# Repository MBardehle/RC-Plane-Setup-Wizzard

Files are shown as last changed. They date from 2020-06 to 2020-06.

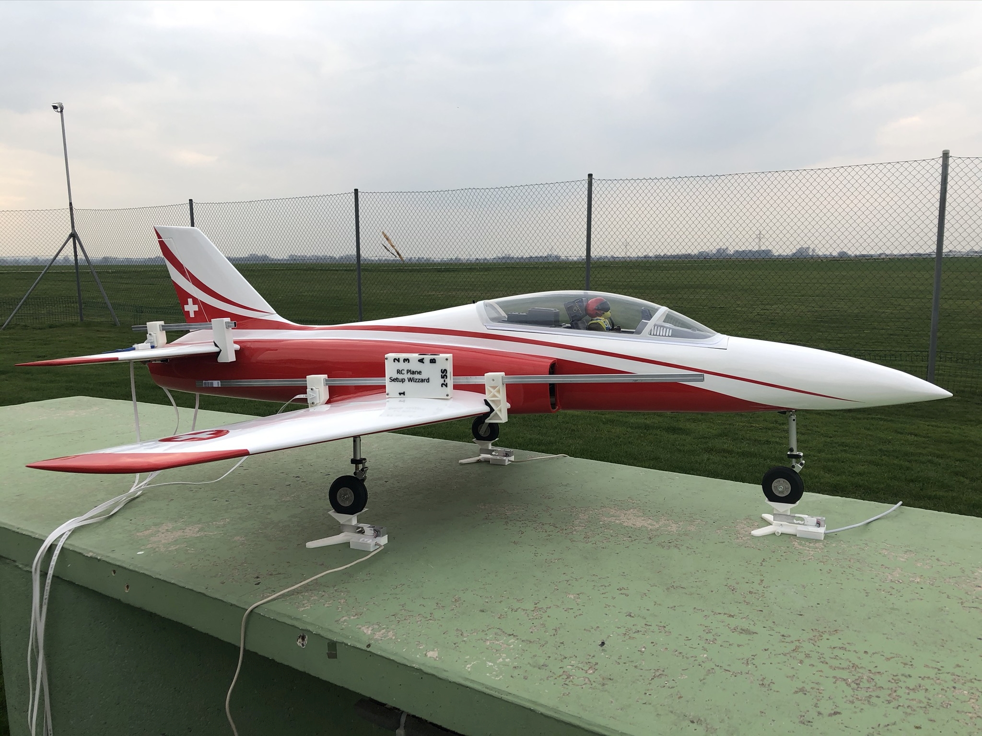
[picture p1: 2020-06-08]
Bilder/Titelbild.jpg

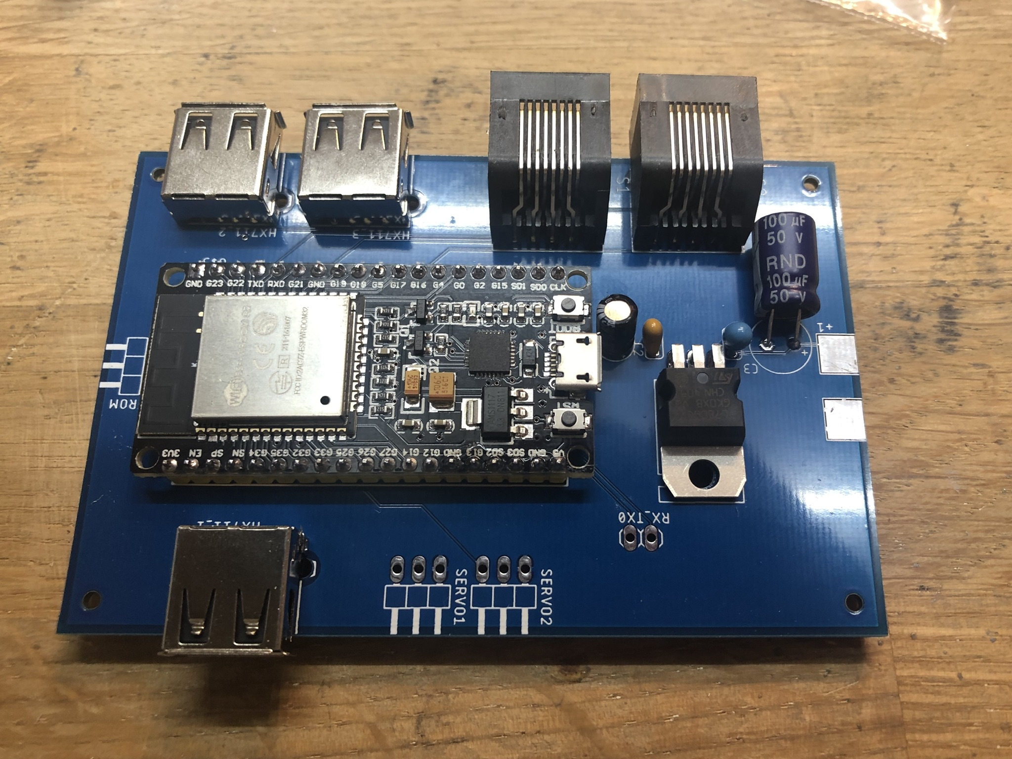
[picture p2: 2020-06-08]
Bilder/Platine.jpg

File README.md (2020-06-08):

# RC-Plane-Setup-Wizzard


Der RC Plane Setup Wizzard kann für die Einstellung der Einstellwinkeldifferenz (EWD), Ruderwinkel und Schwerpunktmessung bei Modellflugzeugen benutzt werden. 

Die benötigte Hardware besteht aus einem ESP32-Microcontroller , 3 Waagen und 2 Beschleunigungssensoren (MMA8451). Das Gehäuse ist für eine selbst erstellte Platine konstruiert worden. Diese kann gegen eine kleine Gebühr bei mir erworben werden. 

Die Sensordaten werden kabellos über eine Bluetooth-Verbindung an eine Android-App übermittelt und angezeigt.

Titelbild

Schwerpunktmessung
Schwerpunktmessung 3

Ruderwinkelmessung mit grafischer Anzeige auf Grenzwertverletzung
Rudermessung

Video_Start

EWD-Messung
EWD-Messung

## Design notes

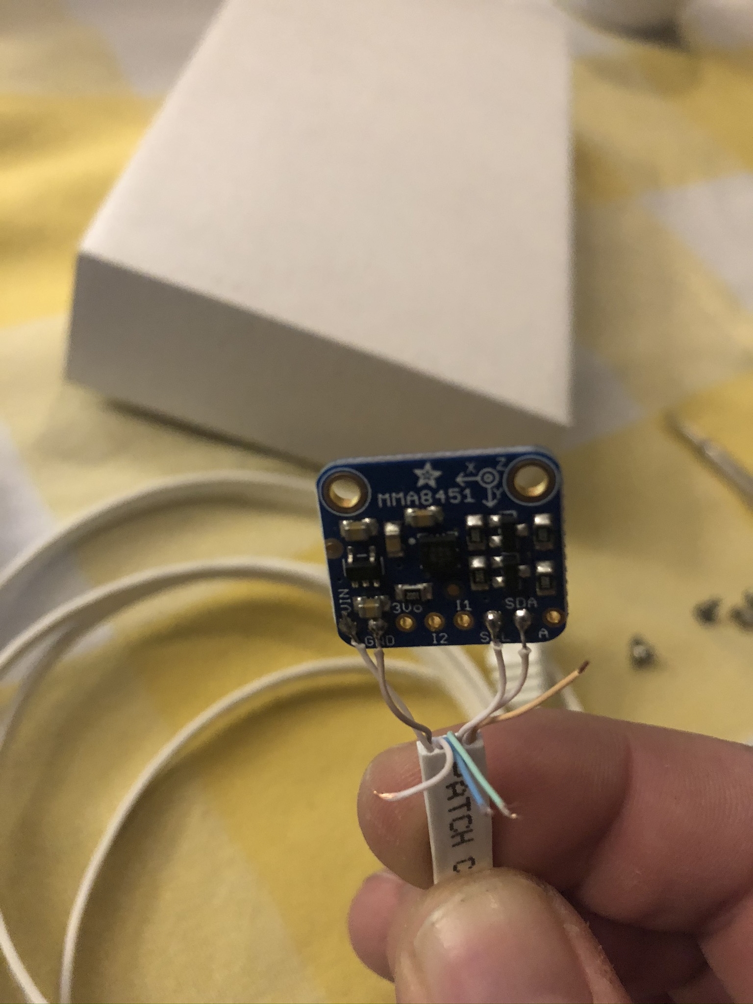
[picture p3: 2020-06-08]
Bilder/MMA8451_Verschaltung.jpg

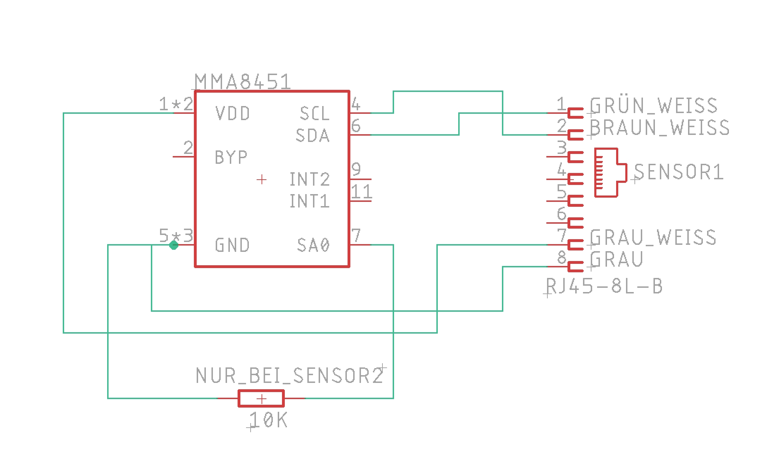
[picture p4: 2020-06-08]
Schaltpläne/Anschluss_MMA8451.jpg

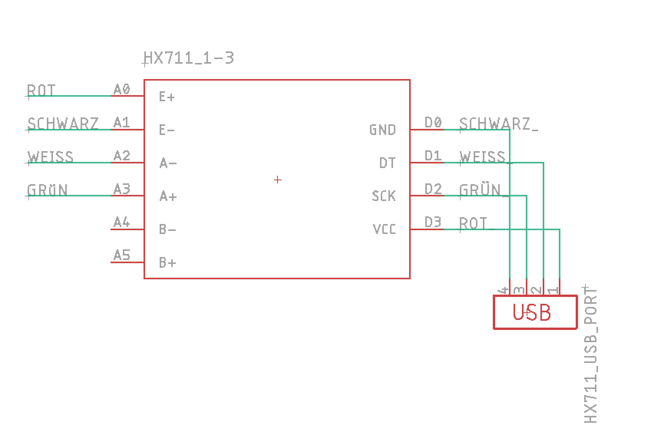
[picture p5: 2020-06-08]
Schaltpläne/Anschluss_HX711.jpg

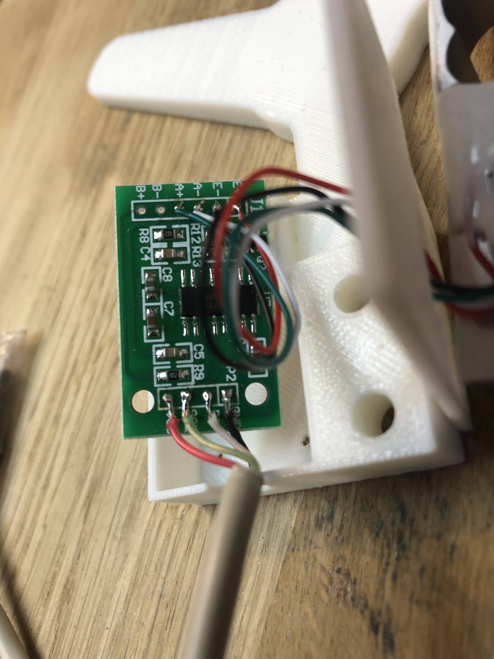
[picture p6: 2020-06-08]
Bilder/HX711_Verschaltung.jpg

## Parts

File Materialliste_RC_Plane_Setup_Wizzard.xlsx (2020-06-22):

Materialliste für RC Plane Setup Wizzard
Anzahl | Artikelbeschreibung | Einzelpreis | Gesamtpreis | Links
1 | 3m Cat.5e, Flach-Patchkabel, weiß | 1.95 € | 1.95 € | https://www.reichelt.de/3m-cat-5e-flach-patchkabel-weiss-goobay-93360-p171122.html?
1 | Widerstand 10k Ohm | 0.08 € | 0.08 € | https://www.reichelt.de/widerstand-kohleschicht-10-kohm-0207-250-mw-5-k-o-rd14jn103t52-p237396.html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
3 | USB 2.0 Kabel, High Speed A Stecker auf B Stecker, ca. 1,8 - 2,0 | 0.95 € | 2.85 € | https://www.reichelt.de/usb-2-0-kabel-high-speed-a-stecker-auf-b-stecker-ca-1-8-2-0-ak-672-2-2-0-p45866.html
2 | Entwicklerboards - Beschleunigungsmesser-Board, MMA8451Q | 9.50 € | 19.00 € | https://www.reichelt.de/entwicklerboards-beschleunigungsmesser-board-mma8451q-debo-sens-acc2-p235519.html
3 | USB-Einbaubuchse, Typ A, gewinkelt, Printmontage | 0.25 € | 0.75 € | https://www.reichelt.de/usb-einbaubuchse-typ-a-gewinkelt-printmontage-rnd-205-00856-p253047.html?
2 | RJ45 8P8C Ethernet Einbaubuchse | 0.42 € | 0.84 € | https://www.reichelt.de/rj45-8p8c-rnd-765-00013-p251918.html?
1 | ESP32 NodeMCU Module | 10.99 € | 10.99 € | https://www.az-delivery.de/products/esp32-developmentboard?_pos=12&_sid=d26cb81a0&_ss=r
1 | gutes ! Micro-USB-Kabel | 1.45 € | 1.45 € | https://www.reichelt.de/sync-ladekabel-usb-a-micro-usb-1-m-goobay-72227-p268018.html?trstct=pos_18&nbc=1
3 | Wiegezellen mit HX711 (Möglich sind 1Kg, 5Kg und 10 Kg) | 4.39 € | 13.17 € | https://www.banggood.com/5KG-Small-Scale-Load-Cell-Weighing-Pressure-Sensor-With-AD-HX711AD-Adapter-p-1129372.html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
1 | Platine für ESP32 (optional) | 15.00 € | 15.00 € | Mail an: marcel.bardehle@gmx.de
2 | Alu-Profil Vierkantprofil 12,5×7,5mm (Bauhaus oder Globus) | 2.05 € | 4.10 € | https://www.bauhaus.info/metallprofile-kunststoffprofile/kantoflex-rechteckrohr/p/10521929
1 | Laser Diode 3V 5mW 650nm rot (6mm dick) | 1.66 € | 1.66 € | https://www.ebay.de/itm/3V-Laser-Diode-5mW-650nm-NIR-nahes-Infrarot-ESP8266-Arduino-Raspberry-Pi/283491860699
1 | Schraubenset Linsenskopf M2.5 (M2.5 x 5 - M2.5x16) z.B. von Amazon | 11.90 € | 11.90 € | https://www.amazon.de/Haobase-Edelstahl-Hexagon-Schrauben-Schraube/dp/B07RBTGT7B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
1 | Schrauben Sonstige (M2.5x6 Senkkopf, M5x20 Senkkopf, M4x16 Zylinderkopf) | 3.00 € | 3.00 €
1 | Set Messing Einpressmuttern M2.5 x 4 x 3.5 (100 Stück) | 7.49 € | 7.49 € | https://www.amazon.de/gp/product/B07SYP6PRJ/ref=ppx_yo_dt_b_asin_title_o09_s00?ie=UTF8&psc=1
1 | Magnet 10 x 2 mm Rund oder Eckig | 1.00 € | 1.00 € | Ebay/Amazon/Hobbyking
 | Kosten für 3D Druck Filament (ca. 500Gramm) |  | 10.00 €
 | Gesamtkosten für das Projekt |  | 105.23 €
Schrauben
Neigungssensoren
Anzahl | Größe
8 | M2.5 x4 Zylinderkopfschraube Neigungssensoren Deckel und Platine
4 | M2.5 x 6 Senkkopfschraube Neigungssensor Boden
4 | M2.5 x 16 Zylinderkopfschraube Verschraubung Neigungssensor mit EWD-Halter
4 | Messing Einpressmuttern M2.5 x 5
Waagen
6 | M5x20 Senkkopfschrauben
6 | M4x16 Zylinderkopfschraube
Gehäuse
4 | M2.5x12 Zylinderkopfschraube
4 | M2.5x5 Zylinderkopfschraube für Platine

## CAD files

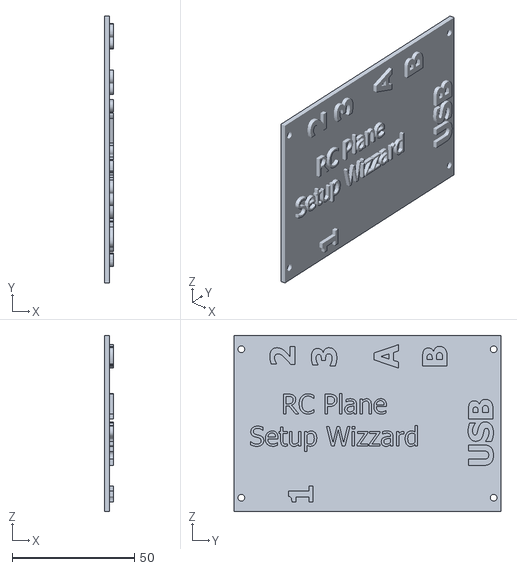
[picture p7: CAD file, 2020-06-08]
3D Files/Gehäuse/Deckel_V11_USB.stl
3.50 x 109.0 x 72.0

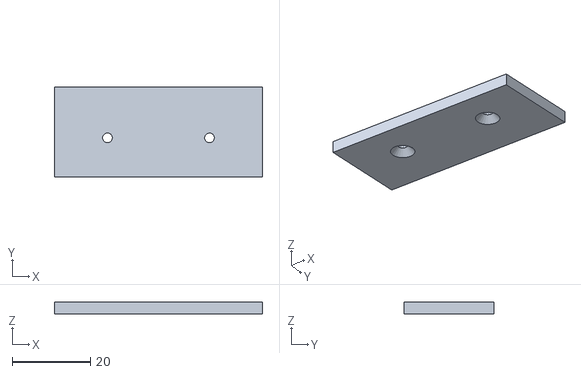
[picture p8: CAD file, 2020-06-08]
3D Files/Neigungssensor/2x Adapter Rudermessung.stl
53.0 x 23.0 x 3.00

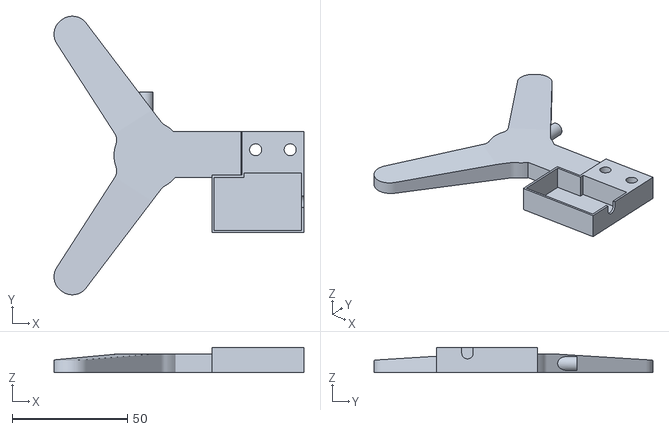
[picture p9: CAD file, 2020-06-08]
3D Files/Waagen/Gehäuse Waage 3 Ziel.stl
108.6 x 121.0 x 11.0

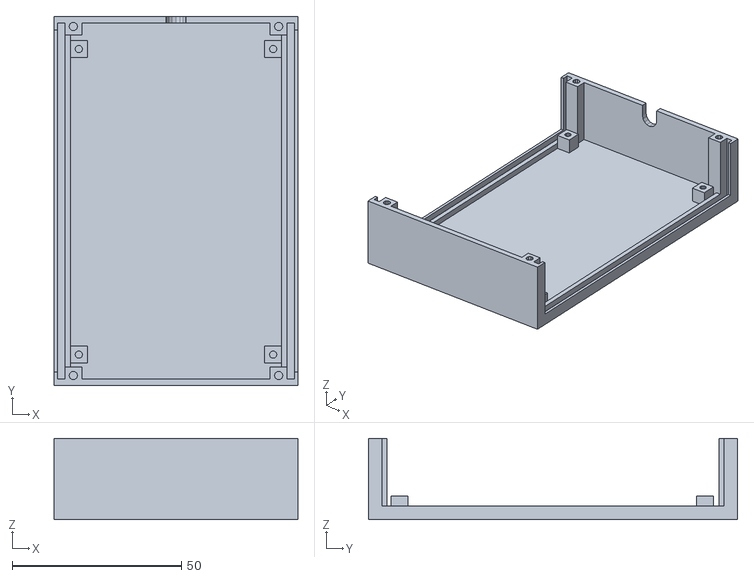
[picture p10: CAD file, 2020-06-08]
3D Files/Gehäuse/Box_USB.stl
72.0 x 109.0 x 24.0

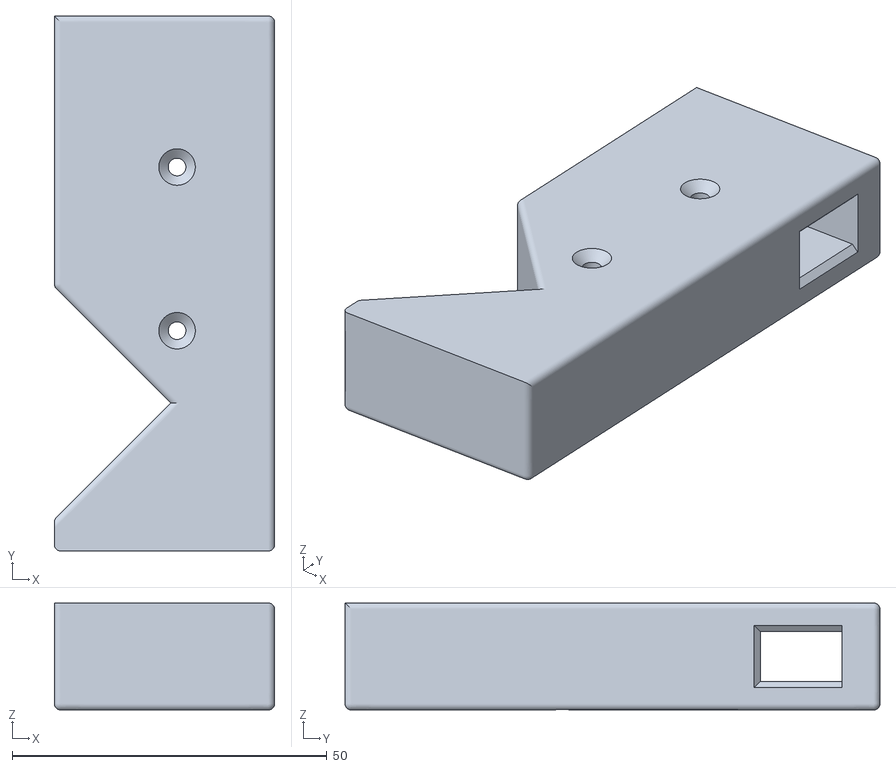
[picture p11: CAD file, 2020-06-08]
3D Files/Neigungssensor/2x EWD_SensorArm_hinten.stl
35.0 x 85.0 x 17.0

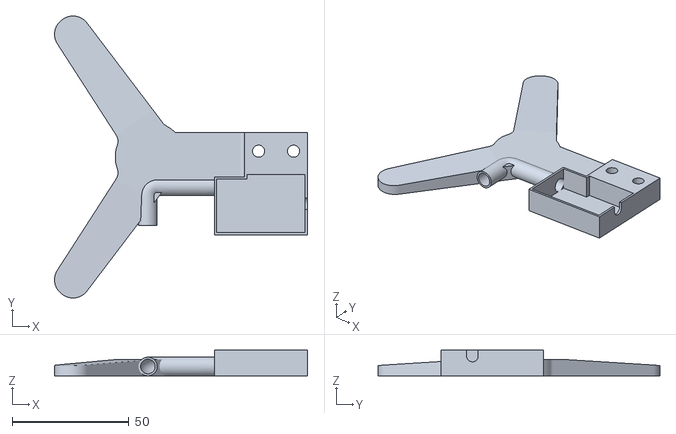
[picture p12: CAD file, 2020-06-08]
3D Files/Waagen/Gehäuse Waage 2 Laser.stl
108.6 x 121.0 x 11.0

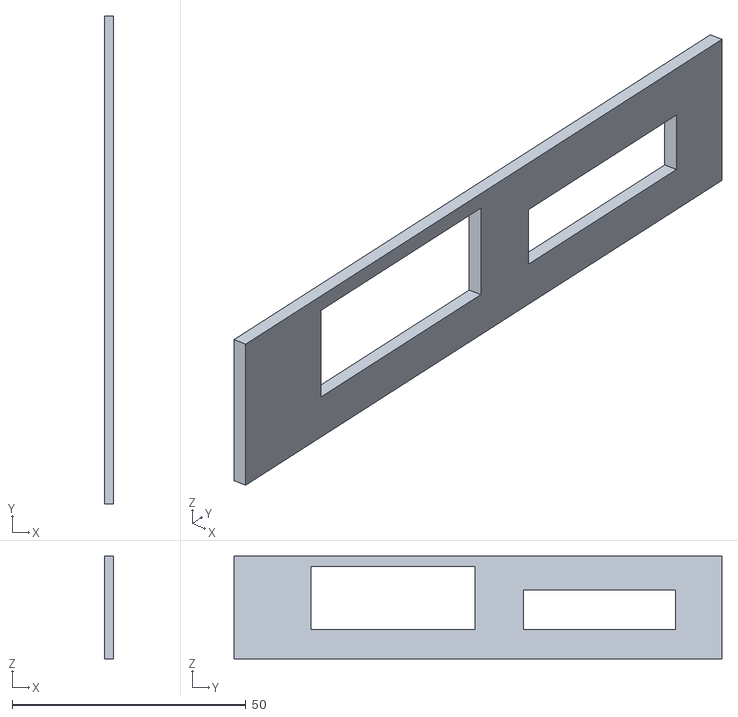
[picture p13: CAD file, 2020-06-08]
3D Files/Gehäuse/Seitenteil_Rechts.stl
2.00 x 104.5 x 22.0

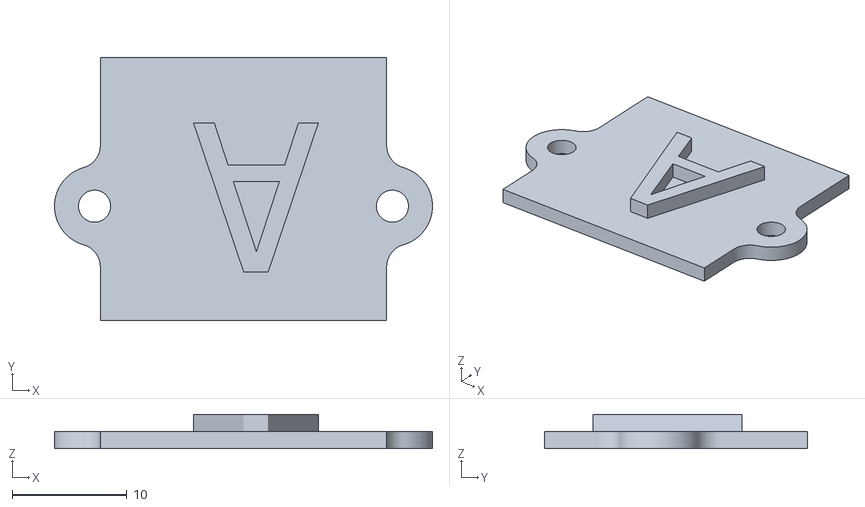
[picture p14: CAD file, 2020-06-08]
3D Files/Neigungssensor/EWD_Deckel_A.stl
33.0 x 23.0 x 3.00

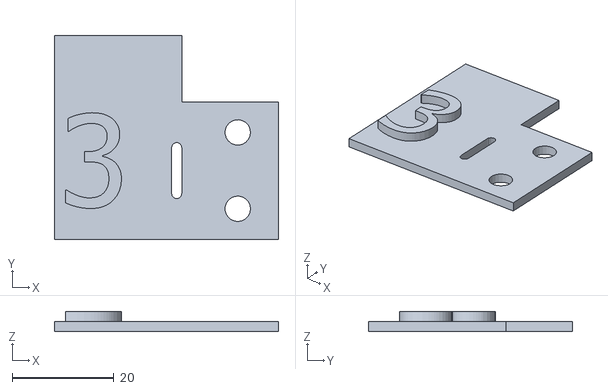
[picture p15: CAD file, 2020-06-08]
3D Files/Waagen/Deckel_3.stl
44.0 x 40.0 x 4.00

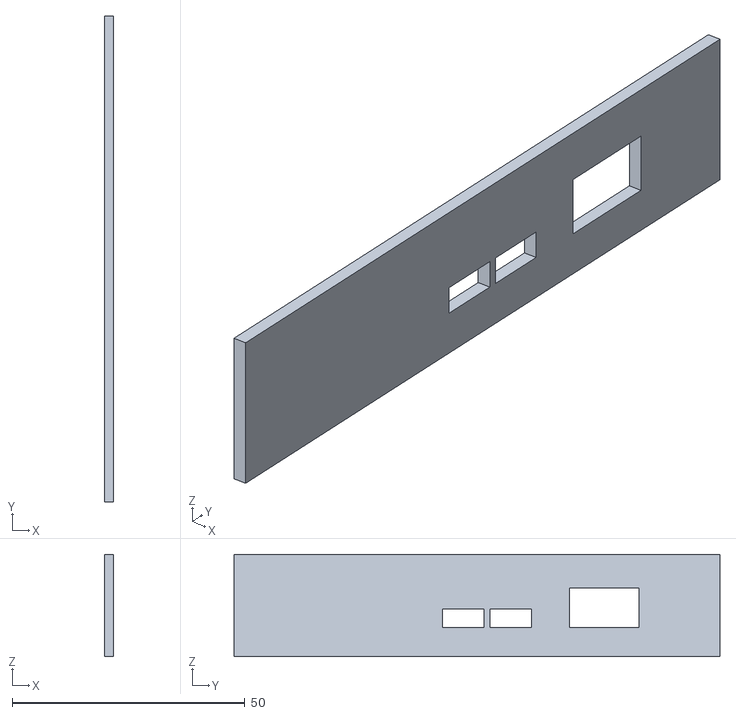
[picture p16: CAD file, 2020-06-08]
3D Files/Gehäuse/Seitenteil_Links.stl
2.00 x 104.5 x 22.0

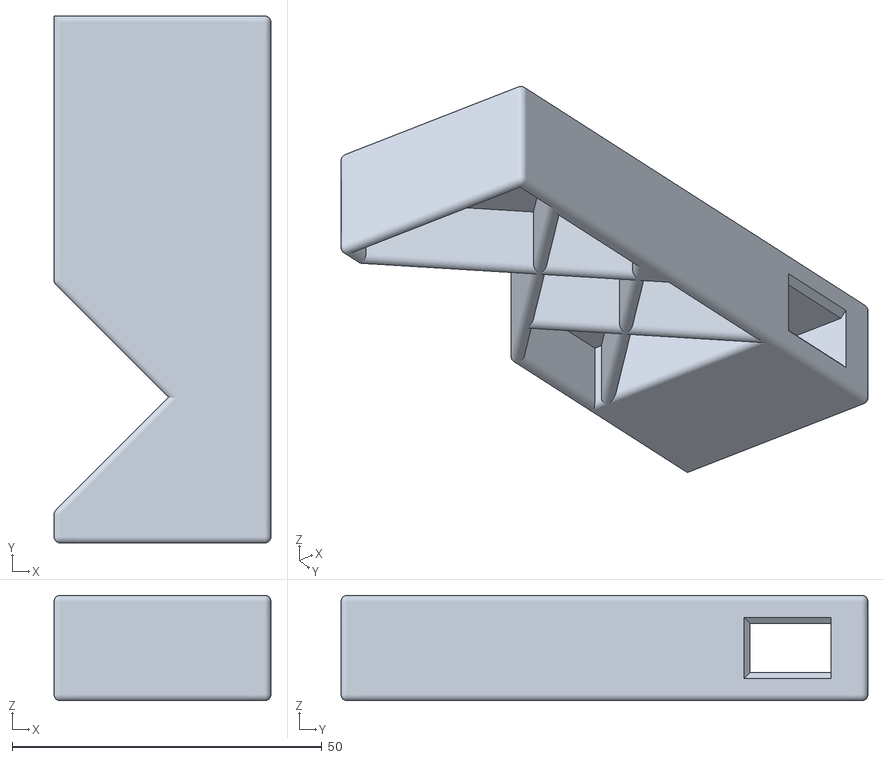
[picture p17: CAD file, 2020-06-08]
3D Files/Neigungssensor/2x EWD_Arm_Vorne.stl
35.0 x 85.0 x 17.0

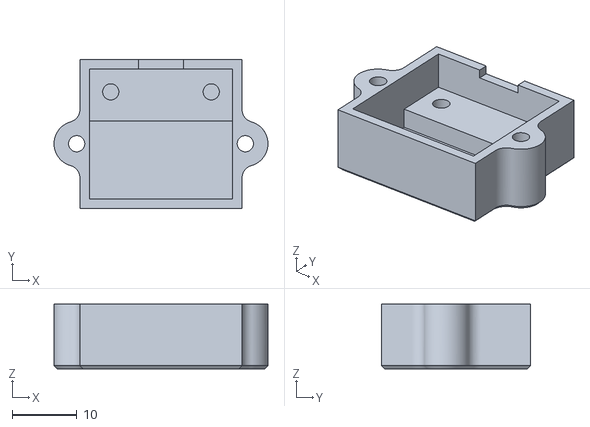
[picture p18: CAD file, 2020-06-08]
3D Files/Neigungssensor/2x EWD_Gehäuse_Sensor.stl
33.0 x 23.0 x 10.0

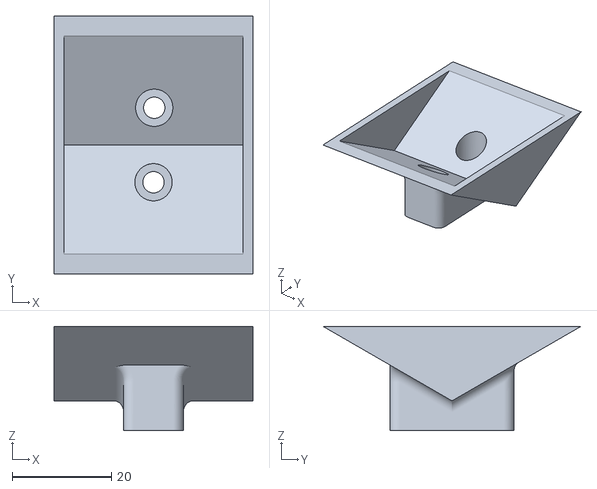
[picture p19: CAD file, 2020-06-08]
3D Files/Waagen/3x Wanne_Eckig.stl
40.0 x 52.0 x 21.0

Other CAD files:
3D Files/Neigungssensor/EWD_Deckel_B.stl
3D Files/Waagen/Deckel_2.stl
3D Files/Waagen/Gehäuse Waage 1 ohne Laser.stl
3D Files/Waagen/Deckel_1.stl

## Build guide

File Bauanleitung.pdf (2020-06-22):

RC Plane Setup Wizzard | Bauanleitung

1

# Bauanleitung RC Plane Setup Wizzard

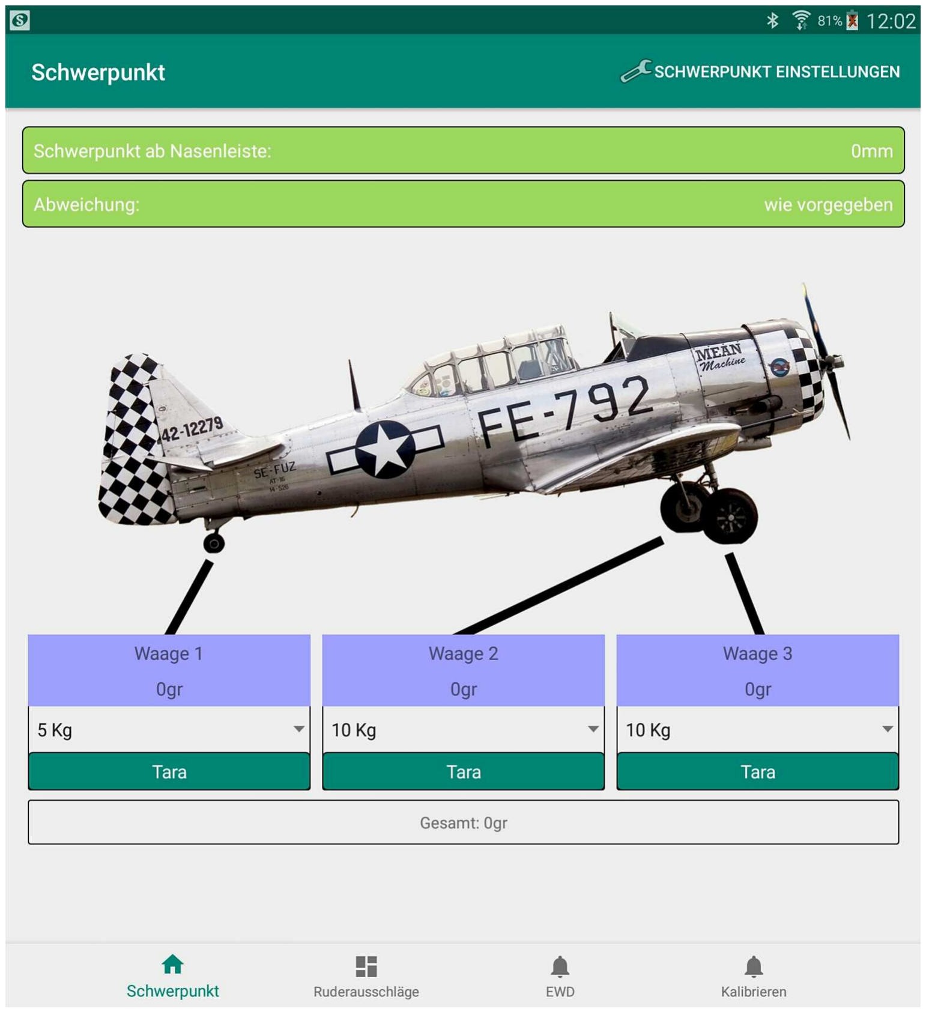
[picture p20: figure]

2

Inhaltsverzeichnis

3

### Vorwort

Das vorliegende Benutzerhandbuch soll Ihnen helfen, die Funktionen des „RC Plane Setup Wizzard“ zu verstehen und das System bedienen zu können. Das Mess-System ist aus der Projektarbeit „PAMF“ (Pilotierung eines appbasierten Messsystems für Fluggeräte) mit den weiteren Personen Gernot Goetz und Thomas Aulich entstanden und wurde nach Fertigstellung der Entwicklung mit dem Produktnamen „RC Plane Setup Wizzard“ betitelt.

Der RC Plane Setup Wizzard ist ein Hilfsmittel, Modellflugzeuge mit Tragflächen vor dem Flug am Boden auszumessen und einstellen zu können. Ein gut eingestelltes Flugmodel nutzt die konstruktionsbedingten Eigenschaften bestmöglich aus. Ein schlecht eingestelltes Flugmodel führt zu schlechten Flugeigenschaften und ggf. zum Absturz. Durch einen Absturz hervorgerufene Schäden können abhängig vom Fluggerät sehr kostspielig sein. Im schlimmsten Fall droht der Totalverlust.

Die folgenden Parameter können mit dem RC Plane Setup Wizzard eingestellt werden:

### 1. Einstellwinkeldifferenz (EWD) zwischen Tragflächen und Höhenruder

### 2. Einstellung des Schwerpunkts auf die errechnete Position

### 3. Einstellung der maximalen Ruderausschläge für die Höhen- und Querruder

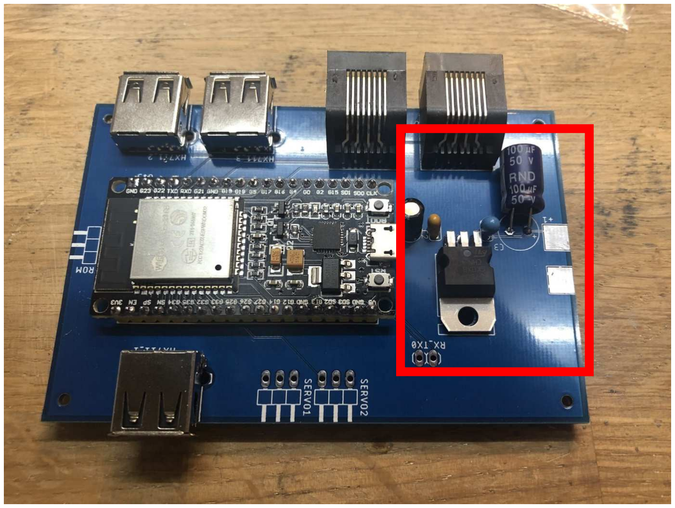
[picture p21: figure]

4

### Aufbau der Platine

Die fertige Platine wird mit folgenden Komponenten bestückt:
- ESP32
- 3x USB Buchse
- 2x RJ-45 Buchse

Es muss genau auf die Ausrichtung des ESP32 geachtet werden.
Die weiteren Bauteile in dem rot markierten Feld werden nicht benötigt.

Die Spannungsversorung des Systems erfolgt direkt über das USB-Kabel, welches am ESP32 angeschlossen wird.

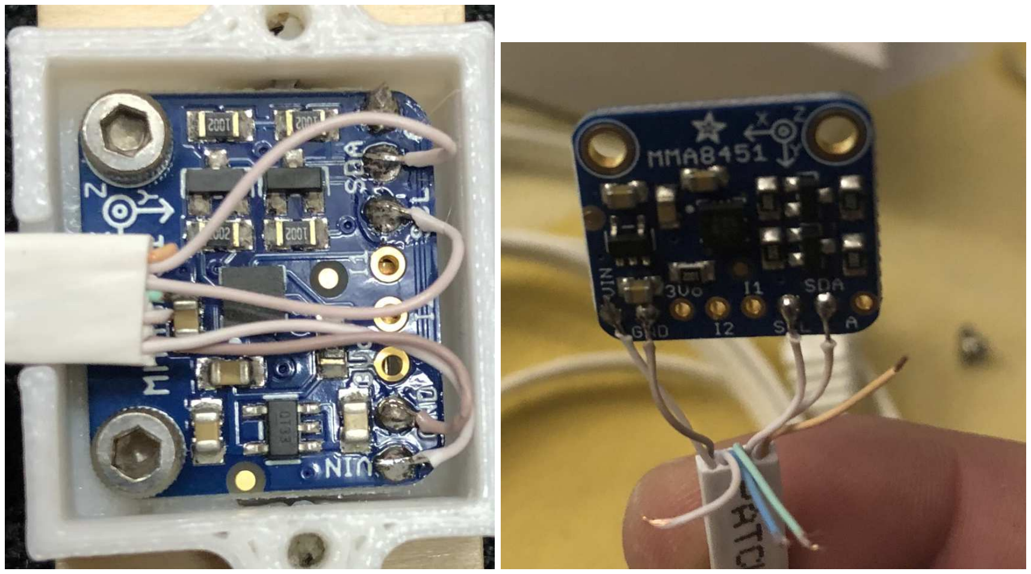
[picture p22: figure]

5

### Aufbau der Neigungssensoren MMA 8451

### 1. Von der Unterseite werden die M2.5 Messing-Einpressmuttern mit einem

Lötkolben bündig mit der Unterseite eingeschmolzen.

### 2. Die Neigungssensoren MMA8451 werden mit M2.5x4 Schrauben im Gehäuse

befestigt.

### 3. Das Ethernet-Kabel mittig durchschneiden. Die Kabellänge von 1,5m je

Sensor darf dabei nicht überschritten werden.
4. Ethernet-Kabel wie auf dem Foto zu sehen anlöten.
5. Für Sensor B einen 10kOhm Widerstand zwischen A und GND anlöten.
6. Verdrahtung gemäß der Tabelle mit Multimeter auf Durchgang prüfen.

Die Adern des Ethernet-Kabels treten immer als Paar auf. Zu jeder Farbe befindet sich auch ein weißer Draht. Mit der Bezeichnung grün/weiß ist der weiße Draht gemeint der zusammen mit dem grünen Draht ein Pärchen ergeben. Die Paare sind nach abisolieren des Kabels zu erkennen.

Pin Sensor | Kabelfarbe | Pin am ESP32
VIN | Grau/Weiss | 3V3
GND | Grau | GND
SDA | Grün/Weiss | 21
SCL | Gelb/Weiss | 22

Auf die RJ45-Buchsen sind zusätzlich die Pins 16/17 verschaltet. Hier ist der 2. I2C-Bus des ESP32 angeschlossen. Diese Pins können für optionale Erweiterungen genutzt werden.

Das flache Ethernet-Kabel kann nach dem Verlöten mit einem Tropfen Sekundenkleber am Gehäuse fixiert werden.

### Aufbau der Wiegeelemente

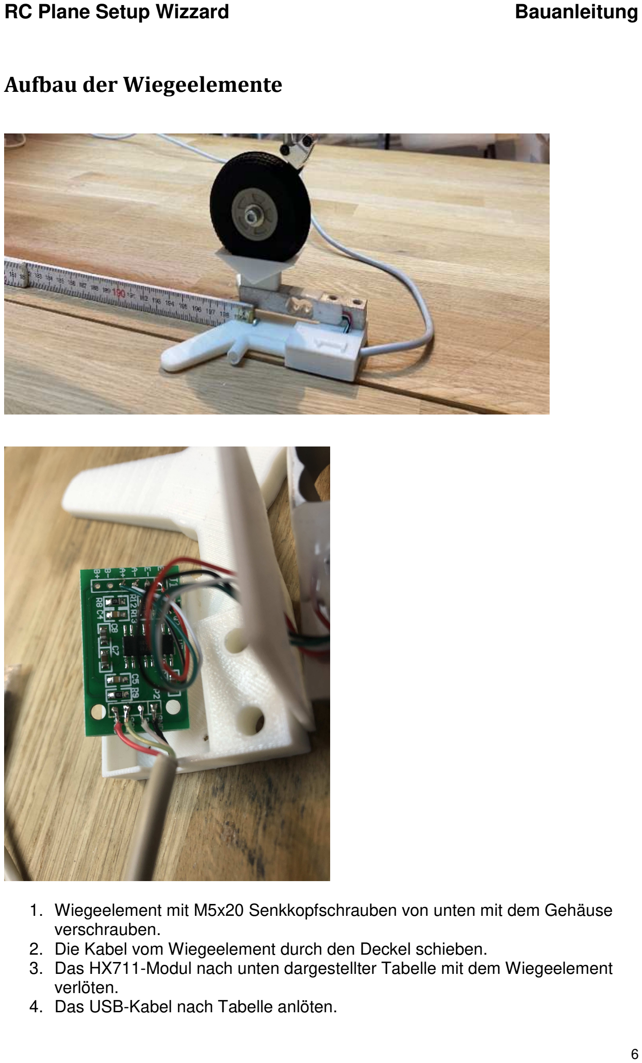
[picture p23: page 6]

6

### 1. Wiegeelement mit M5x20 Senkkopfschrauben von unten mit dem Gehäuse

verschrauben.
2. Die Kabel vom Wiegeelement durch den Deckel schieben.

### 3. Das HX711-Modul nach unten dargestellter Tabelle mit dem Wiegeelement

verlöten.
4. Das USB-Kabel nach Tabelle anlöten.

7

Beim Wiegeelement mit Laser müssen folgende Arbeiten zusätzlich durchgeführt werden
a. Am Laser überstehende Reste vom werksseitigen Löten abschleifen, sodass dieser komplett rund ist.
b. Kabel und Laser in Gehäuse bauen. Laser halb in Gehäuse einschieben, damit später der Fokus noch eingestellt werden kann.
c. Rotes Kabel an VCC / Blaues Kabel an GND anlöten
d. Ausrichtung und Fokus testen
e. Der Fokus kann über die Linse vorne am Laser eingestellt werden. Es sollte ein kleiner starker Punkt ca. 25cm vom Laser entfernt, eingestellt werden. In den meisten Fällen sind die Laser bereits passend voreingestellt.
5. Das Modul mit doppelseitigem Klebeband im Gehäuse fixieren.

### 6. Wiegeelement mit M5x20 Senkkopfschrauben von unten mit dem Gehäuse

verschrauben.

### 7. Reifenwanne vorne mit Waage verschrauben

a. Bei Waage 1 einen Magnet mit den Maßen 10x2mm in den Anschlag für den Zollstock kleben.
Kabelfarbe Waage | Pin am HX711
Rot | E+
Schwarz | E-
Weiß | A-
Grün | A+
Pin HX711 | Kabelfarbe USB | Pin am ESP32
VCC | Rot | 3V3
SCK | Grün | Waage 1: 26
| | Waage 2: 18
| | Waage 3: 32
DT | Weiss | Waage 1: 27
| | Waage 2: 19
| | Waage 3: 33
GND | Schwarz | GND

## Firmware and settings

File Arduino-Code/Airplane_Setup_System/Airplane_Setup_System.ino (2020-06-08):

#include "BluetoothSerial.h"
#include "EWD.h"
#include "CG.h"
#include "Arduino.h"
#include <inttypes.h>


EWD ewd;          //Sensor EWD einfügen
CG cg;            //Schwerpunktwaage einfügen
String btMessage;
String SerialMessage;
bool CG_initOK=false;
bool EWD_initOK=false;
bool RUD_initOK=false;
String function;
String sensor;
String instruction1;
String instruction2;
long timerSend=0.0;
int delaySend=200;

#if !defined(CONFIG_BT_ENABLED) || !defined(CONFIG_BLUEDROID_ENABLED)
#error Bluetooth is not enabled! Please run `make menuconfig` to and enable it
#endif

BluetoothSerial SerialBT;

void setup() {
  Serial.begin(115200);
  SerialBT.begin("Air"); //Bluetooth device name
  Serial.println("The device started, now you can pair it with bluetooth!");
  
  ewd.init();
  cg.init();
}

void loop() {

//Serial.println(btMessage);
char outputText[100];
int i;
int startChar;
int endChar[3];
int endCharCounter=0;
int messageEnd;
long Startmillis;
 if (SerialBT.available()){      // Daten liegen an
   Startmillis=millis();
   
    btMessage = SerialBT.readString(); // Nachricht lesen
    Serial.println(btMessage);
    btMessage.toCharArray(outputText,btMessage.length()+1);     //Zum kopieren muss die Länge +1 genutzt werden, da ansonsten das letzte Zeichen abgeschnitten wird.
    endCharCounter=0;
    messageEnd=0;
    Serial.println(millis()-Startmillis);
    
    for(i=0;i<=btMessage.length();i++)                           //Nach Trennzeichen suchen und Position in endChar-Array speichern
    {
      if(outputText[i]=='#')
      {
        endChar[endCharCounter]=i;
        endCharCounter++;
      }
      if(outputText[i]==';')
      {
        messageEnd=i;
        i=btMessage.length();
      }
    }
    
//  Serial.print("EndChar: ");Serial.println(endCharCounter);  
  function = btMessage.substring(0, endChar[0]);              //Von 0 bis 1. Trennzeichen ist die Funktion
  sensor = btMessage.substring(endChar[0]+1, endChar[1]);     //Von 1.Trennzeichen +1 bis 2. Trennzeichen ist Sensor
  if(endCharCounter>2)                                        //Prüfen ob mehr als 2 Trennzeichen
  {
  instruction1 = btMessage.substring(endChar[1]+1, endChar[2]);         //3 Trennzeichen für Instruction 1 + 2
  instruction2 = btMessage.substring(endChar[2]+1, messageEnd);    
  }
  else{
  instruction1 = btMessage.substring(endChar[1]+1, messageEnd);  //Nur 2 Trennzeichen
  instruction2 = "";
  }
 Serial.print("Function: ");Serial.println(function); 
Serial.print("Sensor: ");Serial.println(sensor);
Serial.print("Instruction 1: ");Serial.println(instruction1);
Serial.print("Instruction 2: ");Serial.println(instruction2);
 endChar[0]=0;
 endChar[1]=0;
 endChar[2]=0;
 messageEnd=0;
 }

if (Serial.available()){      // Daten liegen an
    SerialMessage = Serial.readString(); // Nachricht lesen
    if(SerialMessage == "CG Set Default\n"){
      cg.set_Defaults();
      SerialMessage="";
      cg.init();
    }
    if(SerialMessage == "EWD Set Default\n"){
      ewd.set_Defaults();
      SerialMessage="";
      ewd.init();
    }
}


/***********STring splitten*****/
//  function = btMessage.substring(0, 2);
//  sensor = btMessage.substring(4, 5); 

  if(function=="CG"){
    //Serial.println("if CG Funktion");
    CG_Comm();
  }

  if(function=="EWD"){
    //Serial.println("if CG Funktion");
    EWD_Comm();
  }

  if(function=="RUD"){
    //Serial.println("if CG Funktion");
    RUD_Comm();
  }

}

void CG_Comm(){
  
  int i;
  char outputText[100];
  float calFactor;

  EWD_initOK=false;   //Init der anderen Funktionen zurücksetzen
  RUD_initOK=false;

/* Start Werte automatisch senden */
  if(sensor=="0"&& instruction1=="START"){
    if(CG_initOK==false){
    cg.init(); 
    CG_initOK=true;
    SerialBT.println("CG#0#Start#OK;");
    Serial.println("CG#0#Start#OK;");
    for(i=1;i<=3;i++){
      sprintf(outputText,"CG#%i#%i;", i,cg.get_ldcell_Maxweight(i));
      SerialBT.println(outputText);  
      }
    }
  cg.readSensor();
  sprintf(outputText,"CG#1#%.1f#2#%.1f#3#%.1f;", cg.get_weight(1),cg.get_weight(2),cg.get_weight(3));
  SerialBT.println(outputText);
  Serial.println(outputText);
  
  }

/**** Waage Max-Gewicht setzen ****/  
  if(instruction1=="SET"){          //CG#1#SET#1
    //Serial.print("Sensor: ");Serial.println(sensor.toInt());
    //Serial.print("Inst2: ");Serial.println(instruction2.toInt());
    cg.set_ldcell_Maxweight(sensor.toInt(),instruction2.toInt());
     cg.init(); 
    sprintf(outputText,"CG#%i#SET#%i#OK;", sensor.toInt(), instruction2.toInt());
      SerialBT.println(outputText);  
      Serial.println(outputText);
  function="";
  instruction1="";
  instruction2="";
  }

/*** Waagen nullen ***/
  if(instruction1=="ZERO"){          //CG#0#ZERO
 Serial.println(instruction1);
 
    if(sensor.toInt()==0){
    bool zero1=cg.setZero(1);
    bool zero2=cg.setZero(2);
    bool zero3=cg.setZero(3);
    Serial.print(zero1);Serial.print(zero2);Serial.println(zero3);
      if (zero1==true&&zero2==true&&zero3==true){
        sprintf(outputText,"CG#%i#ZERO#OK;", sensor.toInt());
        SerialBT.println(outputText);  
        Serial.println(outputText);
        }
        else{
        sprintf(outputText,"CG#%i#ZERO#ERROR;", sensor.toInt());
        SerialBT.println(outputText);  
        Serial.println(outputText);    
        }
    }
    else{
      bool zero=cg.setZero(sensor.toInt());
      if (zero==true){
        sprintf(outputText,"CG#%i#ZERO#OK;", sensor.toInt());
//        SerialBT.println(outputText);  
        Serial.println(outputText);
      }
      else{
        sprintf(outputText,"CG#%i#ZERO#ERROR;", sensor.toInt());
//        SerialBT.println(outputText);  
        Serial.println(outputText);    
        }
      
    }
    
  function="CG";
  sensor="0";
  instruction1="START";
  instruction2="";
  }

/*****Status Waage abfragen*/
if(instruction1=="STATUS"){          //CG#1#STATUS--> CG#1#Gewicht#Max-Gewicht#Kalibrierfaktor
  int maxWeight=cg.get_ldcell_Maxweight(sensor.toInt());
  calFactor=cg.getCalFactor(sensor.toInt(),maxWeight);    
  cg.readSensor();    
//  cg.get_weight(1)(sensor.toInt());
    sprintf(outputText,"CG#%i#%.1f#%i#%.2f;", sensor.toInt(),cg.get_weight(sensor.toInt()),maxWeight,calFactor);
      SerialBT.println(outputText);  
      Serial.println(outputText);
  function="";
  instruction1="";
  instruction2="";
  }

/****Kalibrierfaktor auslesen*/
if(instruction1=="GETFAKTOR"){          //CG#1#GETFAKTOR#1
    //Serial.print("Sensor: ");Serial.println(sensor.toInt());
    //Serial.print("Inst2: ");Serial.println(instruction2.toInt());
    calFactor=cg.getCalFactor(sensor.toInt(),instruction2.toInt()); 
    sprintf(outputText,"CG#%i#%i#%.2f;", sensor.toInt(),instruction2.toInt(),calFactor);
      SerialBT.println(outputText);  
      Serial.println(outputText);
  function="";
  instruction1="";
  instruction2="";
  }

/****Kalibrierung Waage frei setzen*/
if(instruction1=="READY"){          //CG#1#READY
cg.startCalibration(sensor.toInt());  
    sprintf(outputText,"CG#%i#READY#OK;", sensor.toInt());
      SerialBT.println(outputText);  
      Serial.println(outputText);
  function="";
  instruction1="";
  instruction2="";
  }


/****Kalibrierung mit Kalibriergewicht*/
if(instruction1=="CAL"){          //CG#1#CAL#Kalibriergewicht in Gramm
cg.calibrateWithKnownWheigt(sensor.toInt(),instruction2.toInt());  
    sprintf(outputText,"CG#%i#CAL#OK;", sensor.toInt());
      SerialBT.println(outputText);  
      Serial.println(outputText);
  function="";
  instruction1="";
  instruction2="";
  }

/****Kalibrierfaktor manuell Anpassen */  
if(instruction1=="ADDFAKTOR"){          //CG#1#ADDFAKTOR#Wert
cg.fineTuneCal(sensor.toInt(),instruction2.toInt());  
    sprintf(outputText,"CG#%i#ADDFAKTOR#OK;", sensor.toInt());
      SerialBT.println(outputText);  
      Serial.println(outputText);
  function="";
  instruction1="";
  instruction2="";
  }  
}


void EWD_Comm(){
  int i;
  char outputText[50];
  bool calOK=false;
  RUD_initOK=false;         //Init der anderen Funktionen zurücksetzen
  
  
/* Start Werte automatisch senden */
  if(sensor=="0"&& instruction1=="START"){
    if(EWD_initOK==false){
    EWD_initOK=ewd.init(); 
      if(EWD_initOK==true){
        SerialBT.println("EWD#0#START#OK;");
        Serial.println("EWD#0#START#OK;");    
        }
        else{
        SerialBT.println("EWD#0#START#ERROR;");
        Serial.println("EWD#0#START#ERROR;");
          function="";
          instruction1="";
          instruction2="";        
        }
    }
  if(EWD_initOK==true){
  ewd.readSensor();
  sprintf(outputText,"EWD#A#%.1f#B#%.1f#AB#%.1f;", ewd.get_SensorA(),ewd.get_SensorB(),ewd.get_SensorDiff());
  SerialBT.println(outputText);
  Serial.println(outputText);
    }
  }

/*** Neigunssensoren nullen ***/
  if(instruction1=="ZERO"){          //EWD#0#ZERO
    if(sensor=="0"){
    ewd.zeroingFunction('A');
    ewd.zeroingFunction('B');
    sprintf(outputText,"EWD#0#ZERO#OK;");
        SerialBT.println(outputText);  
        Serial.println(outputText);
    }   

    if(sensor=="A"){
    ewd.zeroingFunction('A');
    sprintf(outputText,"EWD#A#ZERO#OK;");
        SerialBT.println(outputText);  
        Serial.println(outputText);
    }
    
    if(sensor=="B"){
    ewd.zeroingFunction('B');
    sprintf(outputText,"EWD#B#ZERO#OK;");
        SerialBT.println(outputText);  
        Serial.println(outputText);
    }
  

  function="";
  sensor="";
  instruction1="";
  instruction2="";
  
  /*
  function="EWD";
  sensor="0";
  instruction1="START";
  instruction2="";
  */
 // EWD_initOK=false;
  }
  
/******Sensor A kalibrieren ***/
  if(sensor=="A"&&instruction1=="CAL"){
    calOK= ewd.calibrateSensor(1,SerialBT);
      if(calOK==true){
      SerialBT.println("EWD#A#CAL#OK;");
      Serial.println("EWD#A#CAL#OK;");
      }
      else{
      SerialBT.println("EWD#A#CAL#ERROR;");
      Serial.println("EWD#A#CAL#ERROR;");
      }
    function="";
    instruction1="";
    instruction2="";
  }

/******Sensor B kalibrieren ***/ 
  if(sensor=="B"&&instruction1=="CAL"){
    calOK= ewd.calibrateSensor(2,SerialBT);
      if(calOK==true){
      SerialBT.println("EWD#B#CAL#OK;");
      Serial.println("EWD#B#CAL#OK;");
      }
      else{
      SerialBT.println("EWD#B#CAL#ERROR;");
      Serial.println("EWD#B#CAL#ERROR;");
      }
    function="";
    instruction1="";
    instruction2="";
    }    
} /**Ende EWD-Comm



/***Ruder-Messung */
/* Die Ruder-Messung ist in die Klasse EWD eingebunden, da auf die gleichen Sensoren zugegriffen wird.
 *  Die Funktionen für die Rudermessung fangen mit dem Kürzel "RUD_" an.
 *  Die Initilisierung ist die gleiche wie bei der EWD-Messung
 */
void RUD_Comm(){
  int i;
  char outputText[50];

  EWD_initOK=false;         //Init der EWD-Funktion zurücksetzen
  
/* Start Werte automatisch senden */
  if(sensor=="0"&& instruction1=="START"){
    if(RUD_initOK==false){
    RUD_initOK=ewd.init(); 
    if(RUD_initOK==true){
      ewd.RUD_readSensor();
      //ewd.RUD_zeroingFunction('A');
      //ewd.RUD_zeroingFunction('B');
      SerialBT.println("RUD#0#START#OK;");
      Serial.println("RUD#0#START#OK;");    
      }
      else{
      SerialBT.println("RUD#0#START#ERROR;");
      Serial.println("RUD#0#START#ERROR;");
        function="";
        instruction1="";
        instruction2="";      
      }
    }
  if(RUD_initOK==true){
  ewd.RUD_readSensor();
  //Nur alle 50ms senden
  if(millis()>timerSend){
  sprintf(outputText,"RUD#A#%.1f#B#%.1f#AB#%.1f;", ewd.RUD_get_SensorA(),ewd.RUD_get_SensorB(),ewd.RUD_get_SensorDiff());
  SerialBT.println(outputText);
  Serial.println(outputText);  
  timerSend = millis()+delaySend;  
  }
  //delay(100);
    }
  }

/*** Neigunssensoren nullen ***/
  if(instruction1=="ZERO"){          //EWD#0#ZERO
    if(sensor=="0"){
    ewd.RUD_zeroingFunction('A');
    ewd.RUD_zeroingFunction('B');
    sprintf(outputText,"RUD#0#ZERO#OK;");
        SerialBT.println(outputText);  
        Serial.println(outputText);
    }   

    if(sensor=="A"){
    ewd.RUD_zeroingFunction('A');
    sprintf(outputText,"RUD#A#ZERO#OK;");
        SerialBT.println(outputText);  
        Serial.println(outputText);
        }
    
    if(sensor=="B"){
    ewd.RUD_zeroingFunction('B');
    sprintf(outputText,"RUD#B#ZERO#OK;");
        SerialBT.println(outputText);  
        Serial.println(outputText);
    }
  function="RUD";                     //Automatischer Start nach Tara
  sensor="0";
  instruction1="START";
  instruction2="";
  }

   if(instruction1=="REVERSE"){          //RUD#B#REVERSE;
    if(instruction2=="1"){
    ewd.RUD_set_DiffReverse(true);
    sprintf(outputText,"RUD#B#REVERSE#1#OK;");
    Serial.println("Sensor B Reverse = True");
    SerialBT.println(outputText);  

    }
    if(instruction2=="0"){
    ewd.RUD_set_DiffReverse(false);
    sprintf(outputText,"RUD#B#REVERSE#0#OK;");
    Serial.println("Sensor B Reverse = False");
    SerialBT.println(outputText);  
    }   
  function="RUD";
  sensor="0";
  instruction1="START";
  instruction2="";
  }
  
}

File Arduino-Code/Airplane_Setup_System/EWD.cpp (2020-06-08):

/*SetupBox
	Marcel Bardehle
EWD-Waage mit MMA8451

V0.1

Sensor A = Adresse 0x1D
Sensor B = Adresse 0x1C

/************************************ Includes************************************/                                            
#include "EWD.h"
#include <Arduino.h>
#include "Wire.h"
#include <Adafruit_MMA8451.h>       //https://github.com/adafruit/Adafruit_MMA8451_Library
#include <Adafruit_Sensor.h>        //https://github.com/adafruit/Adafruit_Sensor
#include <Filters.h>                //https://github.com/JonHub/Filters
#include "BluetoothSerial.h"
#include <Preferences.h>


/************************************ DEFINED VARIABLES ************************************/

bool debugging = true;     //Set to true for debugging via serial monitor

float raw_AX, raw_AY, raw_AZ = 0.0; //raw data from sensor A
float raw_BX, raw_BY, raw_BZ = 0.0; //raw data from sensor B

float g_value_AX, g_value_AY, g_value_AZ = 0.0; //g-values from angle sensor A
float g_value_BX, g_value_BY, g_value_BZ = 0.0; //g-values from angle sensor B

float deg_SensorA = 0.0; //Holds the sensor value in degrees
float deg_SensorB = 0.0; //Holds the sensor value in degrees

float deg_RelativeA = 0.0; //FOR ZEROING
float deg_RelativeB = 0.0; //FOR ZEROING

float RUD_deg_SensorA = 0.0; //sensor value for Rudder in degrees
float RUD_deg_SensorB = 0.0; //sensor value for Rudder in degrees

float RUD_deg_RelativeA = 0.0; //FOR ZEROING Rudder
float RUD_deg_RelativeB = 0.0; //FOR ZEROING Rudder

float RUD_deg_SensorA_Round = 0.0; //sensor value for Rudder in degrees
float RUD_deg_SensorB_Round = 0.0; //sensor value for Rudder in degrees

float RUD_smooth_deg_SensorA;
float RUD_smooth_deg_SensorB;

bool RUD_reverse=false;

float filterFrequency = 0.4;    //filters out changes faster than 0.4 Hz
//int average;    //counter for averaging


int offset_AX=0;       // OFFSET values 
int offset_AY=0;   
int offset_AZ=0;

int offset_BX=0;       // OFFSET values
int offset_BY=0;
int offset_BZ=0;

double gain_AX = 0.0;     // GAIN factors
double gain_AY = 0.0;
double gain_AZ = 0.0;  

double  gain_BX= 0.0;     // GAIN factors
double  gain_BY= 0.0;
double  gain_BZ= 0.0;


/*********************************************************************************************/
Preferences preferences;


Adafruit_MMA8451 sensor_A = Adafruit_MMA8451(); //create a sensor object
Adafruit_MMA8451 sensor_B = Adafruit_MMA8451(); //create a sensor object

FilterOnePole lowpassFilter_AX( LOWPASS, filterFrequency );    // create a one pole (RC) lowpass filter 
FilterOnePole lowpassFilter_AY( LOWPASS, filterFrequency );    // create a one pole (RC) lowpass filter
FilterOnePole lowpassFilter_AZ( LOWPASS, filterFrequency );    // create a one pole (RC) lowpass filter

FilterOnePole lowpassFilter_BX( LOWPASS, filterFrequency );    // create a one pole (RC) lowpass filter 
FilterOnePole lowpassFilter_BY( LOWPASS, filterFrequency );    // create a one pole (RC) lowpass filter
FilterOnePole lowpassFilter_BZ( LOWPASS, filterFrequency );    // create a one pole (RC) lowpass filter


//BluetoothSerial SerialBT1;


/************************************ DEFINED FUNCTIONS ************************************/

//This function will run once at startup
bool EWD::init() {
    bool initOK=true;

  Serial.println("EWD Init Start");
  preferences.begin("EWD", false);  //false for read/write
  unsigned int check=preferences.getUInt("check",0);  
  preferences.end();

  //Standard-Parameter schreiben
  if(check!=105){
    
    Serial.println("Init Parameter EWD schreiben");
    preferences.begin("EWD", false);
    preferences.putInt("offset_AX",-36);
    preferences.putInt("offset_AY",48);
    preferences.putInt("offset_AZ",19);

    preferences.putDouble("gain_AX",0.9870573871);
    preferences.putDouble("gain_AY",1.0070818071);
    preferences.putDouble("gain_AZ",0.9926739927);
    
    preferences.putInt("offset_BX",-54);
    preferences.putInt("offset_BY",48);
    preferences.putInt("offset_BZ",-18);

    preferences.putDouble("gain_BX",0.9997557998);
    preferences.putDouble("gain_BY",0.9987789988);
    preferences.putDouble("gain_BZ",0.9919413919);
    preferences.putUInt("check",105);
    //Serial.println(prefs.getUInt("check",0));
    preferences.end();
  }
   
//    if(debugging==true) Serial.begin(9600);

    //check an initialize sensors
    if (sensor_A.begin(0x1D))
    {
      sensor_A.setRange(MMA8451_RANGE_2_G);
      preferences.begin("EWD", true); 
      offset_AX=preferences.getInt("offset_AX",0);
      offset_AY=preferences.getInt("offset_AY",0);
      offset_AZ=preferences.getInt("offset_AZ",0);
      gain_AX=preferences.getDouble("gain_AX",0);     // OFFSET values 
      gain_AY=preferences.getDouble("gain_AY",0);
      gain_AZ=preferences.getDouble("gain_AZ",0);  
      preferences.end(); 


      Serial.println("Sensor A:");
      Serial.print("Offset X: ");Serial.print(offset_AX);Serial.print("  Y: ");Serial.print(offset_AY);Serial.print("  Z: ");Serial.println(offset_AZ);
      Serial.print("Gain X: ");Serial.print(gain_AX,10);Serial.print("  Y: ");Serial.print(gain_AY,10);Serial.print("  Z: ");Serial.println(gain_AZ,10);
      
      if (debugging==true){
        Serial.println("Sensor_A OK!");
        Serial.print("Range A = ");
        Serial.print(2 << sensor_A.getRange());
        Serial.println("G");
        }//end if  
         
    }//end if
     else{
      Serial.println("Sensor A nicht gefunden");
      initOK=false;
      }

    if (sensor_B.begin(0x1C))
    {
      sensor_B.setRange(MMA8451_RANGE_2_G);
      preferences.begin("EWD", true); 
      offset_BX=preferences.getInt("offset_BX",0);
      offset_BY=preferences.getInt("offset_BY",0);
      offset_BZ=preferences.getInt("offset_BZ",0);
      gain_BX=preferences.getDouble("gain_BX",0);     // OFFSET values 
      gain_BY=preferences.getDouble("gain_BY",0);
      gain_BZ=preferences.getDouble("gain_BZ",0); 
      preferences.end();  
      Serial.println("Sensor B:");
      Serial.print("Offset X: ");Serial.print(offset_BX);Serial.print("  Y: ");Serial.print(offset_BY);Serial.print("  Z: ");Serial.println(offset_BZ);
      Serial.print("Gain X: ");Serial.print(gain_BX,10);Serial.print("  Y: ");Serial.print(gain_BY,10);Serial.print("  Z: ");Serial.println(gain_BZ,10);
      
      if(debugging==true){
        Serial.println("Sensor_B OK!");
        Serial.print("Range B = ");
        Serial.print(2 << sensor_B.getRange());
        Serial.println("G");   
        }//end if  
        
    }//end if
     else{
      Serial.println("Sensor B nicht gefunden");
     initOK=false;
     }
    delay(100);
    preferences.end();
    return initOK;
}//end setup
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

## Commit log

2020-06-08 Update README.md
    Der RC Plane Setup Wizzard kann für die Einstellung der Einstellwinkeldifferenz (EWD), Ruderwinkel und Schwerpunktmessung bei Modellflugzeugen benutzt werden. Die benötigte Hardware besteht aus einem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
2020-06-08 Upload
    Upload
    [2x EWD_Arm_Vorne.stl, 2x EWD_Gehäuse_Sensor.stl, 2x EWD_SensorArm_hinten.stl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]
2020-06-08 Create 2x Adapter Rudermessung.stl
    [2x Adapter Rudermessung.stl]
2020-06-09 Upload Materialliste
    [Materialliste_RC_Plane_Setup_Wizzard.xlsx]
2020-06-18 Update Materialliste_RC_Plane_Setup_Wizzard.xlsx
    Falsche Einpressmuttern verlinkt. Wurde jetzt korrigiert.
    [Materialliste_RC_Plane_Setup_Wizzard.xlsx]
2020-06-22 Update App v0.12
    Beim Kalibrieren der Neigungssensoren wird im Step 6 ein neues Bild angezeigt um dem User anzuzeigen, dass die Kalibierung beendet wird. Mit dem nächsten Step werden dann die Werte gespeichert.
2020-06-22 Update Materialliste_RC_Plane_Setup_Wizzard.xlsx
    10kOhm Widerstand und Magnet 10x2mm hinzugefügt
    [Materialliste_RC_Plane_Setup_Wizzard.xlsx]
